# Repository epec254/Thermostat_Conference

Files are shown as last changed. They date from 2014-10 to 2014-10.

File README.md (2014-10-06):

Thermostat_Conference
=====================

## Overview

The following documents detail a 2-hour exercise, in which small teams assemble a prototype of a WiFi controllable "Smart" thermostat.  This activity was developed as a team building exercise at a corporate conference to highlight the maker movement and disruptive potential of open source hardware.  The vast majority of participants were business executives/MBAs with no technical background. The activity was successfully completed by 10 teams ranging in size from 3-10 members in 60-120 minutes, with light guidance from two facilitators.

The activity was inspired by the Spark team's blog post with an "open source" Nest: http://blog.spark.io/2014/01/17/open-source-thermostat/

Because the activity received very positive feedback, we'd like to release the documents for others to repeat.  The forums here at Spark have been incredibly helpful in development of this exercise - we've tried to reference back to specific posts, but likely forgot a few, so please accept our apologies (or, let us know and we will happily add a link).

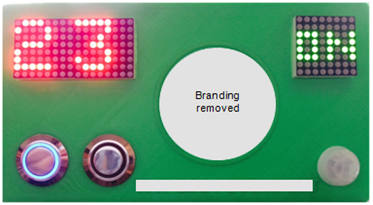
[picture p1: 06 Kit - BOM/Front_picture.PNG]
Picture of device


## Presentation
We kicked off the activity with a ~10 minute PowerPoint presentation.  Apologies for the poor formatting, it is an artifact of removing our company's branding.  I am happy to speak privately about the talk track.

## Participant materials
Each ~10 person team was given a 12 page instruction manual.  We suggested that the team's split themselves into a "hardware" and "software" group.  Progress was checked at 5 "checkpoints", where teams were measured on speed to completion.

## Participant code
Pre-written code was provided to each team.  The code corresponds to the checkpoints in the instruction manual & requires a few easy changes to be made by each team.

## Participant webapp
A HTML5 / JavaScript based interface allowed each team to view the status of / control their thermostat.  It is based on the recently released SparkJS library.  It was hacked together quickly, so I'm sure my CS professor wouldn't be so proud of the code quality ;)  I've flagged several places for future TODOs if anyone is so inclined.

## Contest tracking
As mentioned above, it was a contest to see which team could get to each checkpoint first.  To track this, in the pre-written code, a line in the setup() routine published an event to the Spark API with the team's current status.  While easily "hacked" and by no means the most elegant solution, it worked for our purposes.  An HTML file listened for the published event & displayed the timestamp for each checkpoint -- we projected this.  An (unfortunate) limitation of this HTML file is that if you refresh the page, all timestamp data is cleared.

To overcome this limitation, a node.js application listened for the same event & logged timestamps to a CSV file.  The included Excel file allows simple processing of this data to determine a winner.  Instructions for getting node.js working on Windows can be found here: https://community.spark.io/t/tutorial-spark-cli-on-windows-01-oct-2014/3112

* *Live_Status_Page.html:* HTML5 / JavaScript page that listens for each checkpoint & displays timestamps on screen (Based on: http://community.spark.io/t/multiple-cores-publishing-to-one-web-page/4161)
* *Example_Live_Results.html:* Example of what the live status page could look like post exercise
* *eventLogger.js:* Node.JS application to log the timestamps for each checkpoint (Based on https://community.spark.io/t/spark-publish-nodejs-and-eventsource-solved/3901/2)
* *Score Calculator and Dashboard vPublic.xlsx:* Excel tool to post-process data from eventLogger.js

## Pre-conference setup
To avoid potential issues and simplify, each Spark was pre-configured to a unique account & configured with a local WiFi network (instructions for how to do this can be found in the Spark documentation http://docs.spark.io/connect/).  The Spark team suggested that we use a 2.4Ghz only (e.g., turn off 5Ghz) 802.11b / g only access point with WPA2.  The access point was configured on an otherwise unused channel (e.g., at the conference center, we had IT turn off all other WiFi networks on the channel used).

## Kit / BOM
Each team needs the following components.  Note, the Adafruit LED matrixes require a small amount of soldering (<5 mins / kit).  As well, we soldered wires to the buttons for simplicity, but you could also use wire with quick connects or similar.

A basic Fritzing diagram is included.  It is for visual display only, so we only built out the breadboard tab.  We opted to not share this with participants as we thought it would be "too easy."   Our helpers had this in hand when they walked around the session in case a team was struggling - although it turned out this was unnecessary.

* (1) Spark Core: https://www.spark.io/
* (2) LED display - red: http://www.adafruit.com/products/870
* (1) LED display - green: http://www.adafruit.com/products/872
* (1 bundle) Wire bundles: http://www.adafruit.com/products/153
* (1) Cooling button: http://www.adafruit.com/products/481
* (1) Heating button: http://www.adafruit.com/products/559
* (1) USB power: http://www.adafruit.com/products/501
* (1) Temp sensor: http://www.adafruit.com/products/165
* (1) Capacitor (10000 pf): http://www.digikey.com/product-detail/en/K103K15X7RH5TL2/BC1111CT-ND/286733
* (1) Motion sensor: http://www.parallax.com/product/28033
* (15 cables) Jumper cables: Either one works, but the parallax ones have a slightly tighter fit around the LED jumper pins: http://www.parallax.com/product/800-00047 or https://www.adafruit.com/products/824
* (2) 10k ohm resistor: Purchased as part of this kit: https://www.sparkfun.com/products/10969, but any resistor will work!
* (1) 220 ohm resistor: Purchased as part of this kit: https://www.sparkfun.com/products/10969, but any resistor will work!
* (optional): USB power source, required if your participants will not have laptops to plug the Sparks into

## Thermostat enclosure
Each team was provided a 3D printed "faceplate" in which all components could be inserted.  We opted to have attendees super glue the components in place vs. "perfectly" engineer the faceplate.  For the demonstration unit, we designed a box that enclosed the entire device - great for a "wow" factor.  We used a LulzBot TAZ 4, which we would recommend, primarily due to their support team going above & beyond in helping us setup / configure the printer.

In case it helps someone, we included a version of the "faceplate" that has the beginnings of more "perfect" engineering but it is completely untested & currently not very 3D printer friendly.

The STL & Autodesk Inventor files are available.

* *Cover_Split_Top-vPublic:* "Faceplate" provided to each attendee (note - we embossed our conference name / logo but have removed here - https://github.com/epec254/Thermostat_Conference/blob/master/07%20Thermostat%20enclosure/Cover_Split_Top-vPublic.png)
* *Cover_Split_Bottom-vPublic:* Bottom of the "faceplate" to make it snap into the top of the box (printed separately and "acetone glued" to the top)
* *Box_Square_Bottom v3:* Box to enclose entire device, note that it does not fit a power source and requires you to shorten all wires (just used for the demo unit - https://github.com/epec254/Thermostat_Conference/blob/master/07%20Thermostat%20enclosure/Box_Square_Bottom%20v3.png)
* *Cover_Split_Bottom-Needs Support Material vPublic*: More "engineered" but completely untested bottom for the "faceplate"

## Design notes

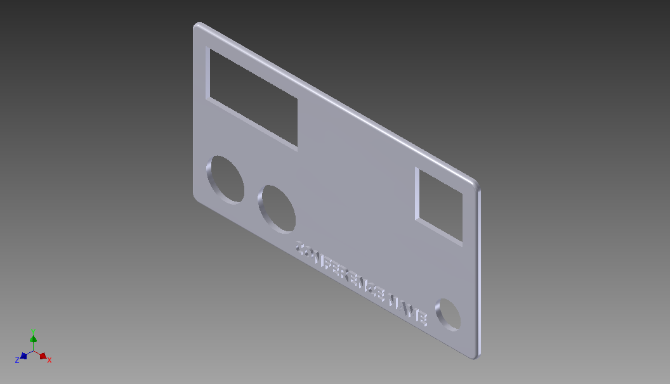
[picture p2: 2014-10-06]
07 Thermostat enclosure/Cover_Split_Top-vPublic.png

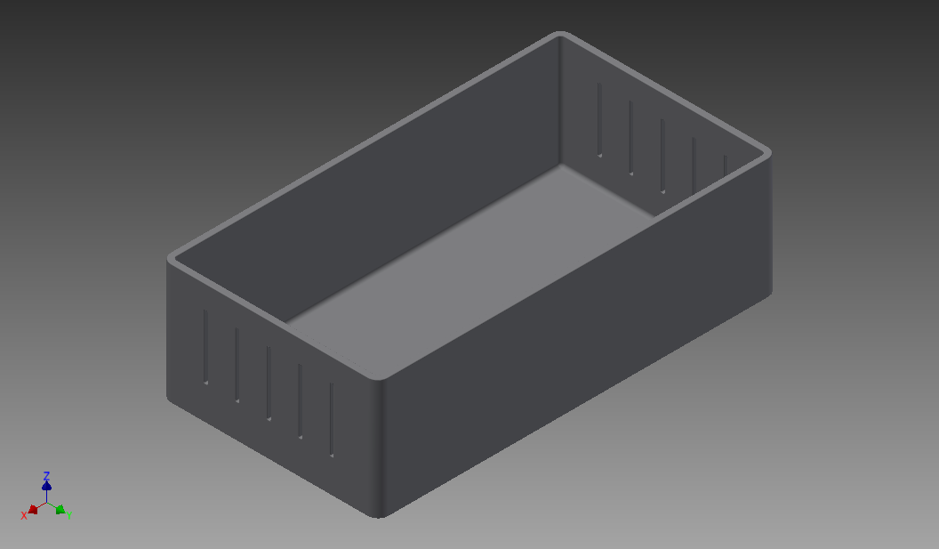
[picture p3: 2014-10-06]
07 Thermostat enclosure/Box_Square_Bottom v3.png

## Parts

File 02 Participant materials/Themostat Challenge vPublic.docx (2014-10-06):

TEAM PROGRAMMING CHALLENGE

This challenge is designed to demonstrate how widely-available open-source hardware and software can be used to quickly prototype new products. You will be using the components in front of you to build a prototype of WiFi-controllable "smart" thermostat.

The following instructions incrementally build the thermostat prototype, but there are opportunities to parallel process between the hardware assembly and software steps (each step is labeled either Hardware or Software). We suggest organizing your team into a hardware and software team.

In addition to completing the assembly and programming tasks, each team will also be required to develop a sales pitch, which will be judged qualitatively (see final steps in instructions for details).

BILL OF MATERIALS

Each kit should have the following components:

1. (1) 3D Printed mouting board

2. (1) SparkCore chip & breadboard

3. (1) Power supply & USB Charger

4. (1) Motion sensor

5. (1) Temperature sensor

6. (3) LED matrices

7. (3) Resistors

8. (2) Push buttons

9. (1) Capacitor

10. Connecting wires

11. (4) Jumper cables

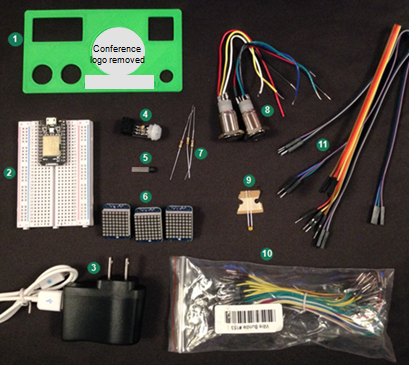
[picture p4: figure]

ACTIVITY INSTRUCTIONS

1. HARDWARE: Learning to use a breadboard

An electronics breadboard is a component to prototype circuits without the need for soldering.

Under the plastic covering, a breadboard contains horizontal and vertical rows of metal strips

The horizontal rows allow you to electrically connect a given component to any other component placed on that same row (up to 5 components), by inserting pins into the plastic pin holes. It is important to note that the 5-pin rows on each side are not connected.

The vertical strips on the left and right are called power rails and are connected across all rows. This gives the builder easy access to a power source. The power strips on both sides are also not connected.

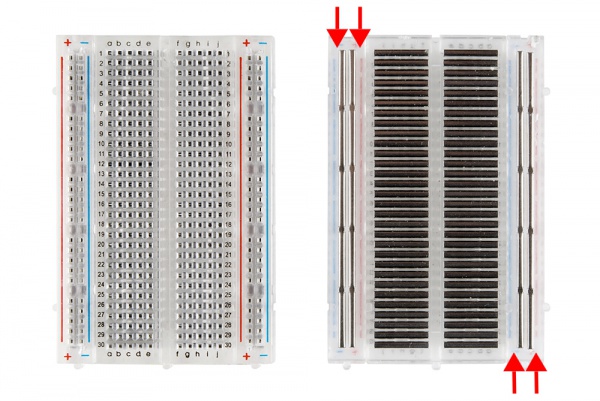
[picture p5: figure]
Front and back, medium breadboard with power rails exposed

"Connecting wires" are easily inserted into the plastic peg holes, creating circuits without soldering.

Example wiring

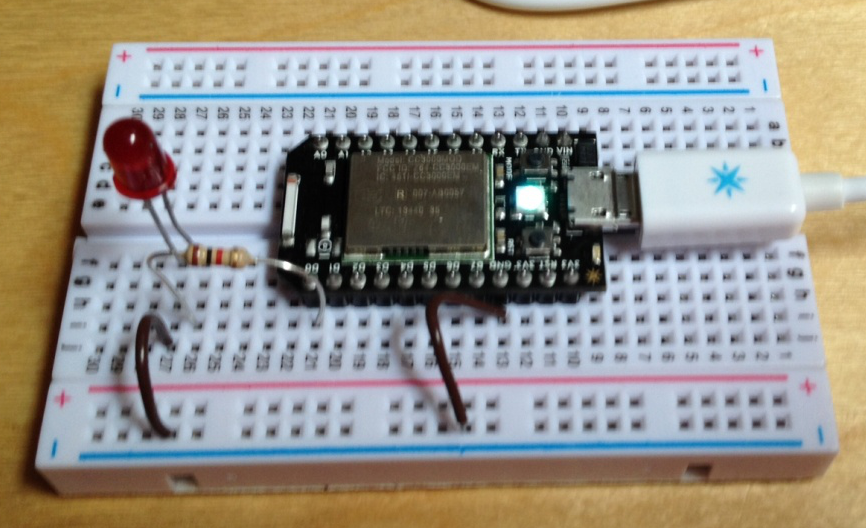
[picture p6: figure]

2. HARDWARE: Connect your SparkCore to power

2.1. Disconnect SparkCore from breadboard (gently wiggle it out) and reconnect as shown below, such that the Spark core's A0 pin aligns with the breadboard's row 12.

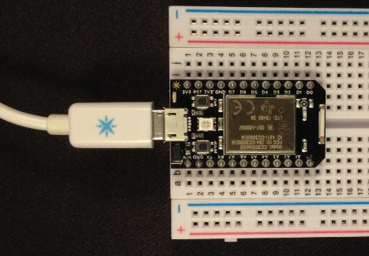
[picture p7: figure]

2.2. Connect SparkCore to power supply (connect the USB to a computer or plug included in the BOM)

  - When powered on you should see a blue "breathing" light

2.3. Do not push the two small black buttons on the SparkCore at any point (this resets the base software)

3. SOFTWARE: Upload initial software package

The Spark OS has a distributed operating system, where servers in the Cloud do the heavy lifting. That way the product can handle complex, intelligent behaviors when it's online, even with only kilobytes of memory.

4.1. Go to https://www.spark.io/build and login using the following credentials and the number that was written on your Spark's box

4.2. Name your Current App "ThermostatApp"; press enter

4.3. Now add a custom library of code to simplify our program.

- Click the Libraries icon (banner-icon 4th up from the bottom left)
- Type Therm
- Click Therm_LED_Library
- Scroll down and click "Include in App" button

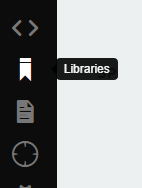
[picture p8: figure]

Now we want to add code to our device. In the spirit of open source software, we've written most of the code for you.

4.4. Go to Step1.cpp and copy the entire block of code

4.5. Return to the Spark build website and paste code into your "Current App" replacing all existing code

- The top of the window where you are pasting code should say "thermostatapp.ino"

4.6. In line 9 of the code, change your CoreID to match the number written on the Spark's box (e.g. 7)

4.7. In line 10 of the code, change your TeamName to something creative and unique! (This will appear on the leader board projected in the room)

- E.g. char *teamName = "Witty Team Name"; //max length 20 characters!!!

4.8. Click the verify logo (second down from top) to confirm your code compiles correctly; you should see "Code Verified! Great work" message on bottom right

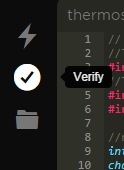
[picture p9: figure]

4.9. Click the flash button (see image below) to send your new code to your Spark (this will take a moment)

- The light on the spark chip will go through a series colors and blinking (it will first flash purple), before returning to blue "breathing"

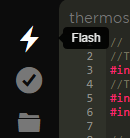
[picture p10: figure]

Color code:

- Flashing green: Connecting to Wi-Fi network
- Flashing cyan: Connecting to Spark Cloud
- Breathing cyan: Connected to Spark Cloud
- Flashing purple: Updating firmware

_____________________________________________________________________________________

!!! CHECK-POINT #1 !!!

Congrats, you've earned your first points!

In the next 60 seconds, the dashboard projected in the room should show that your team has completed this step.

_____________________________________________________________________________________

5. HARDWARE: Connecting temperature chip to your breadboard

You're now ready to connect your first component to your breadboard!

5.1. Connect the breadboard's (-) power rail to SparkCore's GND connection point using a connecting wire

5.2. Connect the breadboard's (+) power rail to SparkCore's 3V3* connection point using a connecting wire (make sure it is 3V3*, not 3V3), (hint the wire will arc over the chip)

5.3. Insert temperature sensor's three pins into breadboard's B28, B29, B30

5.4. Connect temperature chip's Pin1 and Pin3 to appropriate power rails using connecting wires (see graphic below)

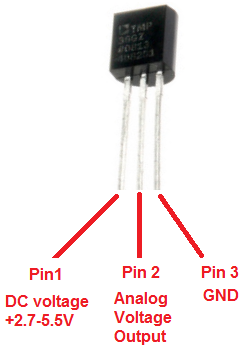
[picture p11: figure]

5.5. Insert capacitor (see BOM) connecting breadboard's ground power rail on A-E side of board, to breadboard's A5

5.6 . Using a connecting wire, connect Pin2 of temperature chip to spark core's A7 (your connecting wire should be placed into breadboard's B5)

You now need to sync with the software team to update the device's software and read the temperature! They will need to know what Spark pin you have connected the temperature sensor to.

_____________________________________________________________________________________

!!! CHECK-POINT #2 !!!

In the next 60 seconds, the dashboard projected in the room should show that your team has completed this step.

_____________________________________________________________________________________

6. SOFTWARE: Reading temperature from device

You're now ready to wirelessly flash new software to your device and read the temperature!

6.1. Go to Step2.cpp and copy the block of code

6.2. Return to the Spark build website and paste code into your "Current App" replacing all existing code

- Recall, the top of the window where you are pasting code should say "thermostatapp.ino"

6.3. In the code, change the following (prior changes are lost when new code updated, sorry!)

- Line9: Change your CoreID to match the number written on your Spark's box (e.g. 7)
- Line10: Update your TeamName again

6.4. In line 16 of the code, you need to replace the "xx" with Spark's connection point that the thermostat's output wire is connected to. Ask your Hardware team for this information based on what they completed in step 5. Do not use quotes (e.g. #define THERM_PIN A3)

6.5. Click the verify button (second down from top) to confirm your code compiles correctly; you should see "Code Verified! Great work" message on bottom right.

6.6. Click the flash button (see image below) to send your new code to your Spark (this will take a moment)

- The light on the spark chip will go through a series colors and blinking (it will first flash purple), before returning to blue "breathing"

7. SOFTWARE: Mobile Access

Because your device is cloud connected, you can access it from any mobile device. To demonstrate this we've set up a simple mobile website available <insert website location>

7.1. Open the website

7.2. Login using your credentials from your BOM

7.3. Confirm the temperature on your phone your previous/current reading

Congrats! You've built a WiFi-accessible thermometer! But we can do more!

_____________________________________________________________________________________

!!! CHECK-POINT #3 !!!

In the next 60 seconds, the dashboard projected in the room should show that your team has completed this step.

_____________________________________________________________________________________

8. HARDWARE: Connecting LED Matrices

Now we'd like to be able to display the temperature directly to the device.

8.1. Connect 4-stranded jumper cables to your three LED Matrices (order does not matter, but push hard to ensure connection is made)

8.2. Connect the LED's +/- and negative connection points to your power strips in rows ~21-23 using the jumper cables (Do this for all three LED matrices)

- Look at the top of the LED matrix to match the given jumper cable strand to its connection point.
- You may want to tear back the wires/apart some to give you more room to manipulate


8.3 For each LED Matrix, connect its "C" connection point to row 21 on the A-E side of the breadboard; For "D" connection point, connect to row 22.

8.4. Create a connection between the LED Matrix pin "C" and Spark's D1 (should be breadboard's row 11) using a connecting wire via rows 21.

8.5. Create a connection between the LED Matrix pin "D" and Spark's D0 (should be breadboard's row 12) using a connecting wire via rows 22.

LED trouble shooting: If an LED is not working, disconnect the Spark's power source and reconnect.

You now need to sync with your software team. They will need to know what Spark pins you have connected the LEDs to.

9. SOFTWARE: Display temperature on LED Matrix

We need to update the code to utilize the hardware team's new LED matrices.

9.1. Go to Step3.cpp and copy the block of code

9.2. Return to the Spark build website and paste code into your "Current App" replacing all existing code

9.3. In the code, change the following (prior changes are lost when new code updated, sorry!)

- Line 9: Update your CoreID
- Line 10: Update your TeamName

9.4. Now update Lines 17 and 18 for I2C_D and I2C_C. To update these ask your hardware team which of Spark's PINs they connected to the LED matrices' C and D connection points.

- For example, if the hardware team advised it was connected to A0, the code be: #define I2C_D A0

9.5. Click the verify logo (second down from top) to confirm your code compiles correctly

9.6. Click the flash button to send your new code to your Spark (this will take 15-30 seconds and the devices will flash purple)

_____________________________________________________________________________________

!!! CHECK-POINT #4 !!!

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

_____________________________________________________________________________________

10. HARDWARE: Wire buttons to set temperature

Next we want the ability to set the temperature vs. read it. We'll add two buttons to do this.

10.1. Connect the breadboard's other power strips (the F-J side) to Spark's GND and 3V3* connection points using connecting wires.

10.2 Unscrew nut from bottom of push button; pass wires through front of 3D printed mounting board; re-thread nut (place blue-LED to left; Red to right)

10.3. Connect the black wires from both push buttons to the ground power rail (suggest rows 29/30 on F-J side)

10.4. Connect the red power wire directly to breadboard holes…(DO NOT CONNECT TO POWER RAIL)

- For blue button, connect to breadboard i7 (which should connect to Spark's D5 connection point)
- For red button, connect to breadboard i6 (which should connect to Spark's D6 connection point)

10.5. Find the wire on each button that is closest to the black ground wire (color should be white or blue), and plug it into the + power rail (suggest ~rows 15/16 on F-J side)

10.6. Now we need to connect a resistor to the board to limit the flow of electricity through the circuit (this is known as a pull down resistor, but we don't need to get into the details).

- Find the (2) identical resistors in your BOM with the black stripe
- Plug one end of the resistor into the ground power rail (F-J side) and the other end into row 24 (rows F-J); with the second resistor, do the same between the ground power rail and row 27.

10.7. Complete the circuit using the button, resistor, and spark

- For the blue push button, take the remaining unattached wire and connect to breadboard's row 27 (F-J side)
- For blue push button, use a connecting wire to complete the circuit to Spark's D2 (should be at breadboard's row 10) connection point from breadboard's row 27
- For the red push button, take the remaining unattached wire and connect to breadboard's row 24 (F-J side)
- For red push button, use a connecting wire to complete the circuit to Spark's D3 (should be at breadboard's row 9) connection point from breadboard's row 24

11. SOFTWARE: Set temperature

We need to update the code to utilize the hardware team's new push buttons.

11.1. Go to Step4.cpp and copy the block of code

11.2. Return to the Spark build website and paste code into your "Current App" replacing all existing code

11.3. In the code, change the following (prior changes are lost when new code updated, sorry!)

- Line 9: Update your CoreID
- Line 10: Update your TeamName

11.4. Click the verify logo (second down from top) to confirm your code compiles correctly

11.5. Click the flash button to send your new code to your Spark (this will take a moment)

_____________________________________________________________________________________

!!! CHECK-POINT #5 !!!

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

_____________________________________________________________________________________

12. HARDWARE: Connect motion sensor device

Lastly, we want to add a motion sensor so we can introduce logic based on the activity around the device.

12.1. Connect motion sensor to 3–stranded jumper cable (you may want to tear back the wires to give you more room to manipulate them)

12.2. Thread the jumper cables through the front of the 3D printed mounting board.


12.3. Connect the motion sensor's "VDD" point to power (+) on the breadboard's F-J side (suggest row ~5)

12.4. Connect the motion sensor's "GND" point to ground (-)on the breadboard's F-J side (suggest row ~5)

12.5. Find the remaining resistor (Red-Red-Brown-Gold) and connect breadboard's G15 and G17

12.6 Connect the remaining jumper cable strand (motion sensor's "Out") to F15

12.7 Use a connecting wire to connect breadboard's F17 to Spark's D4 (should be breadboard's row 8)

Congrats, your hardware is now fully wired! You need to speak with your software team to tell them where you've wired the motion sensor.

13. SOFTWARE: Motion sensor

We need to update the code to utilize the hardware team's motion sensor.

13.1. Go to Step5.cpp and copy the block of code

13.2. Return to the Spark build website and paste code into your "Current App" replacing all existing code

13.3. In the code, change the following (prior changes are lost when new code updated, sorry!)

- Line 9: Update your CoreID
- Line 10: Update your TeamName

13.4. Now update Line 25 with the Spark pin that the hardware team connected the motion sensor to.

- For example, if the hardware team advised it was connected to A0, the code be: #define Motion A0

13.4. Click the verify logo (second down from top) to confirm your code compiles correctly

13.5. Click the flash button to send your new code to your Spark (this will take a moment)

_____________________________________________________________________________________

!!! CHECK-POINT #5 !!!

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

_____________________________________________________________________________________

14. Final assembly

14.1. Use super glue (shared across groups) to fix your LEDs and motion sensor to the mounting board

14.2. Gently bend wires to stand display upright. Take a picture and smile.

The electronics of your prototype could be encased into a 3D printed housing (see sample).

Appendix: Example circuits (not part of this design)


Programming Activity

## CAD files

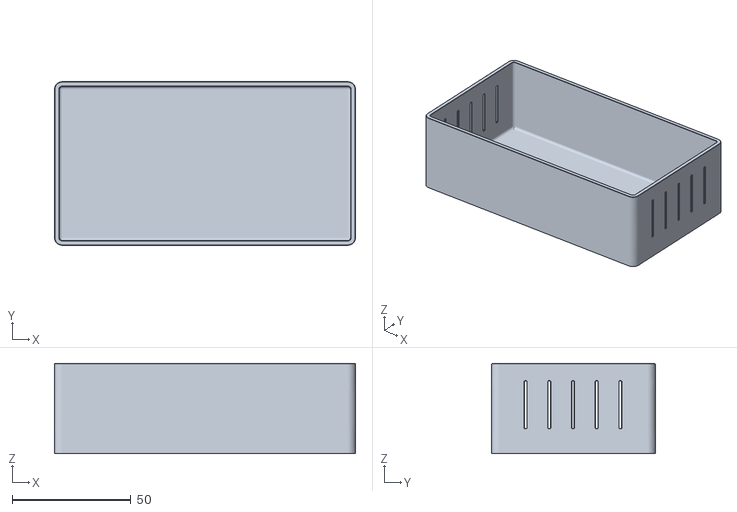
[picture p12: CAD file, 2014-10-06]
07 Thermostat enclosure/Box_Square_Bottom v3.stl
127.0 x 69.0 x 38.1

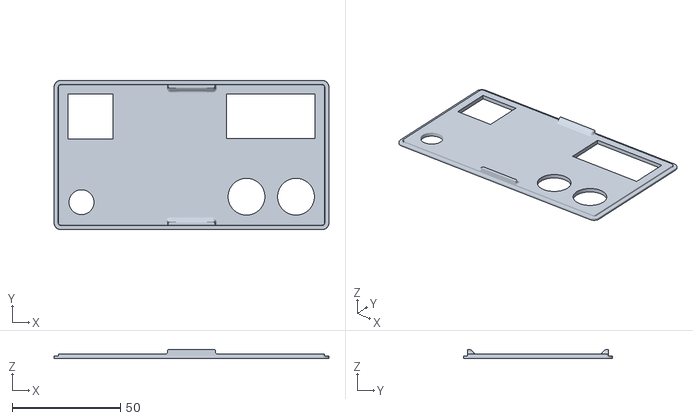
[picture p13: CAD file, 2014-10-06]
07 Thermostat enclosure/Cover_Split_Bottom-vPublic.stl
127.0 x 69.0 x 4.00

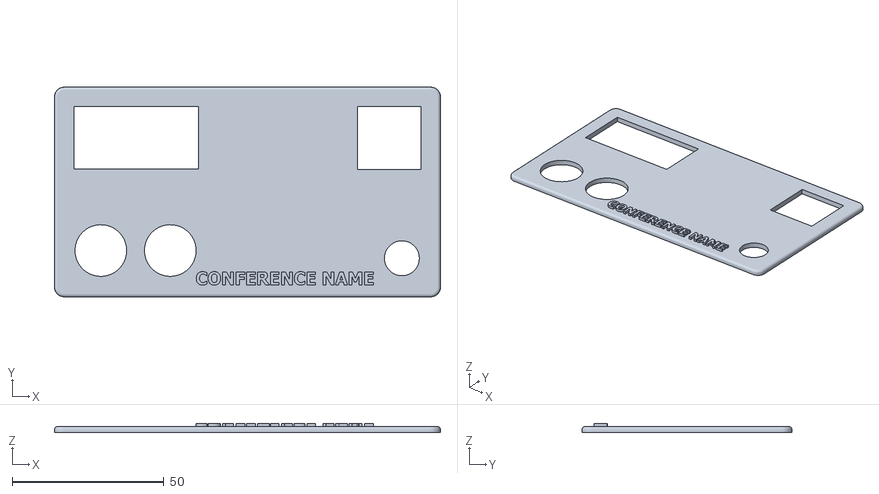
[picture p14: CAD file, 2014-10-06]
07 Thermostat enclosure/Cover_Split_Top-vPublic.stl
127.0 x 69.0 x 3.00

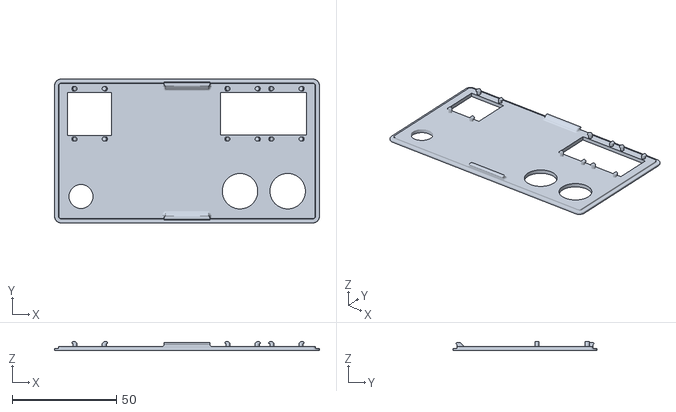
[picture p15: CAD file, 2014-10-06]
07 Thermostat enclosure/Cover_Split_Bottom-Needs Support Material vPublic.stl
127.0 x 69.0 x 4.53

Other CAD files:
07 Thermostat enclosure/Box_Square_Bottom v3.ipt
07 Thermostat enclosure/Cover_Split_Bottom-Needs Support Material vPublic.ipt
07 Thermostat enclosure/Cover_Split_Bottom-vPublic.ipt
07 Thermostat enclosure/Cover_Split_Top-vPublic.ipt

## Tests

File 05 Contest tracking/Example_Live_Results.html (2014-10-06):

#### Team status

Team Name | Team ID | Stage 1 | Stage 2 | Stage 3 | Stage 4 | Stage 5
A perfect fit | 10 | 2014-10-02T08:47:07.987Z | 2014-10-02T08:58:47.705Z | 2014-10-02T09:12:10.074Z | 2014-10-02T09:30:01.328Z | 2014-10-02T09:40:57.122Z
Absolute Zeroes | 14 | 2014-10-02T08:49:00.809Z | 2014-10-02T08:57:44.260Z | 2014-10-02T09:05:05.363Z | 2014-10-02T09:07:30.058Z | 2014-10-02T09:21:38.371Z
BlueAngels | 11 | 2014-10-02T08:50:24.151Z | 2014-10-02T08:52:48.805Z | 2014-10-02T09:01:32.420Z | 2014-10-02T09:05:04.780Z | 2014-10-02T09:13:53.456Z
Winning23 | 23 | 2014-10-02T08:50:41.940Z | 2014-10-02T08:54:45.386Z | 2014-10-02T09:05:01.194Z | 2014-10-02T09:11:01.475Z | 2014-10-02T09:15:49.706Z
Thermax | 22 | 2014-10-02T08:56:06.512Z | 2014-10-02T08:59:56.194Z | 2014-10-02T09:08:16.548Z | 2014-10-02T09:17:43.936Z | 2014-10-02T09:21:41.329Z
SmrtBOX | 21 | 2014-10-02T08:57:30.716Z | 2014-10-02T09:00:52.324Z | 2014-10-02T09:14:02.205Z | 2014-10-02T09:16:55.191Z | 2014-10-02T09:23:53.116Z
Nested-If | 24 | 2014-10-02T08:58:45.391Z | 2014-10-02T09:06:50.470Z | 2014-10-02T09:19:46.422Z | | 2014-10-02T09:35:23.522Z
iMeter | 13 | | 2014-10-02T09:03:34.880Z | 2014-10-02T09:15:04.473Z
Thermonator | 9 | 2014-10-02T09:16:35.565Z

Running

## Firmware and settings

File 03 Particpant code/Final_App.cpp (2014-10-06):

// This #include statement was automatically added by the Spark IDE.
//This will allow for future support of the LED matrixes
#include "Therm_LED_Library/Therm_LED_Library.h"
//These next 2 lines are required by spark
#include "application.h"
#include <math.h>

//now we will declare your team name
int core_id = 1; //change to your spark team ID (1 - 30)
char *teamName = "Demo Unit"; //max length 20 characters!!!

//now you need to ask your hardware team what PIN your different items are on 
//change XX in the code below to the pin number, e.g., D6, etc
//(if your hardware team tells you thermostat is connected to D6 code would be as follows)
//#define THERM_PIN   D6
//button toggles
#define COOL_BUTTON D2
#define HEAT_BUTTON D3
//LEDs within the buttons
#define COOL_LED D5
#define HEAT_LED D6
//Thermometer
#define THERM_PIN   A7
//Motion sensor
#define MOTION D4

//static definitions to identify which pin belongs to which device
//DO NOT CHANGE
#define MATRIX1_I2C 0x70
#define MATRIX2_I2C 0x71
#define MATRIX3_I2C 0x72
#define I2C_D D0
#define I2C_C D1
#define MAX_TEMP 40
#define MIN_TEMP 0
#define DESIRED_TEMP_FLASH_ADDRESS 0x80000
Adafruit_8x8matrix matrix1;
Adafruit_8x8matrix matrix2;
Adafruit_8x8matrix matrix3;

//DO NOT CHANGE THESE NEXT LINES
//These store the current state of the program
//variable to store current temperature (the room)
int currentTemperature = 0;
//variable to store desired temperature (the setting)
int desiredTemperature = 0;
//should the heat be on?
bool isHeatOn = false;
//should the AC be on?
bool isCoolOn = false;
//is motion currently detected?
bool motionDetected = false;
//last time motion detected
unsigned long lastMotionSensed = 0UL;
//UNIX timestamp of last motion sense
int lastMotionTimeStamp = 0;
//to log data via google apps
char logResult[200] = "";
//to allow motion to only be published to the cloud once every 15 seconds
unsigned long lastMotionPublish = 0UL;
char idForPublishMotion[2] = "";
//last state of cool / heat buttons
int lastHeatButtonState = 0;
int lastCoolButtonState = 0;
//to allow thermostat to turn on / off
//true = on; false = off
bool thermostatStatus = true;
//status variable
char statusString[100] = "";
char *contestStatus = "step5";

static const uint8_t on_motion[] = {
    0b11111111,
    0b00000000,
    0b11101001,
    0b10101101,
    0b10101011,
    0b11101001,
    0b00000000,
    0b11111111
};

static const uint8_t off_motion[] =
{   0b11111111,
    0b00000000,
    0b11101111,
    0b10101000,
    0b10101111,
    0b11101000,
    0b00000000,
    0b11111111 };

static const uint8_t on_nomotion[] =
{   0b00000000,
    0b00000000,
    0b11101001,
    0b10101101,
    0b10101011,
    0b11101001,
    0b00000000,
    0b00000000 };
static const uint8_t off_nomotion[] =
{   0b00000000,
    0b00000000,
    0b11101111,
    0b10101000,
    0b10101111,
    0b11101000,
    0b00000000,
    0b00000000 };

void displayTemperature(void);
void saveTemperature();
void loadTemperature();
int setTemperature(int t);
int setTemperatureFromString(String t);
void setupMatrix(Adafruit_8x8matrix m);
int adjustThermostatStatus(String status);



//run by the Spark Core upon start - configures all PINs & web interface
void setup()
{
    Wire.begin();
    
    //initial setup of the LED matrixes
    matrix1.begin(MATRIX1_I2C);
    matrix2.begin(MATRIX2_I2C);
    matrix3.begin(MATRIX3_I2C);
    
    setupMatrix(matrix1);
    setupMatrix(matrix2);
    setupMatrix(matrix3);
    
    //allow temperature to be set via web interface
    Spark.function("set_temp", setTemperatureFromString);
    
    //allow thermostat to be turned on / off from web interface
    Spark.function("set_status", adjustThermostatStatus);
    
    //allow temperature (room & setting) to be read from web interface
    Spark.variable("current_temp", &currentTemperature, INT);
    Spark.variable("desired_temp", &desiredTemperature, INT);
    
    //allow status of heating & cooling & motion to be read from web interface
    Spark.variable("is_heat_on", &isHeatOn, BOOLEAN);
    Spark.variable("is_cool_on", &isCoolOn, BOOLEAN);
    Spark.variable("motion", &motionDetected, BOOLEAN);
    
    //Variable that Google docs will read
    Spark.variable("log_data", &logResult, STRING);
    
    Serial.begin(9600);
    
    loadTemperature();
    
    //LED pins send voltage (OUTPUT)
    pinMode(COOL_LED, OUTPUT);
    pinMode(HEAT_LED, OUTPUT);
    
    //themometer pin recieves voltage (INPUT)
    pinMode(THERM_PIN, INPUT);
    
    //temp setting buttons recieve voltage (INPUT)
    pinMode(COOL_BUTTON, INPUT);
    pinMode(HEAT_BUTTON, INPUT);
    
    //motion senior recieves voltage (INPUT)
    pinMode(MOTION, INPUT);
    
    //default LEDs to off
    digitalWrite(COOL_LED,LOW);
    digitalWrite(HEAT_LED,LOW);
    
    sprintf(statusString, "{\"id\":%d,\"team\":\"%s\",\"contest_status\":\"%s\"}", core_id, teamName, contestStatus);
    Spark.publish("contest-status",statusString);
}



void loop()
{
    //counter to allow us to only check the temp every so often
    static int wait = 0;
    
    static int firstTimeOn = 1;
    
    int tempReading = 0;
    double voltage = 0.0;
    
    int motionReading = 0;
    
    int heatButtonState = 0;
    int coolButtonState = 0;
    
    
    //only check & update temp every so often
    if (!wait)
    {
        wait = 1000;
        
        //TEMPERATE READING
        //read temp raw data
        tempReading = analogRead(THERM_PIN);
        voltage = (tempReading * 3.3) / 4095;
        //get the temp as degrees C
        double doubleTemp = (voltage - 0.5) * 100;
        //convert c to f
        //doubleTemp = ((doubleTemp * 9) / 5) + 32;
        // cast to int (e.g., change 75.44 to 75)
        currentTemperature = round(doubleTemp);
    }
    
    //MOTION READING
    motionReading = digitalRead(MOTION);
    if (motionReading == HIGH) {
        motionDetected = true;
        //store last time sensed
        lastMotionSensed = millis();
        lastMotionTimeStamp = Time.now();
        
        //only publish every 15 seconds
        unsigned long now = millis();
        if ((now - lastMotionPublish)>15000UL) {
            sprintf(idForPublishMotion, "%d", core_id);
            Spark.publish("contest-motion",idForPublishMotion);
            lastMotionPublish = now;
        }
    } else {
        motionDetected = false;
    }
    
    
    //BUTTONS FOR TEMP ADJUSTMENT
    heatButtonState = digitalRead(HEAT_BUTTON);
    coolButtonState = digitalRead(COOL_BUTTON);
    
    if(heatButtonState == HIGH) { //button pressed
        
        if (lastHeatButtonState != heatButtonState) { //changed from previous state
            //this logic prevents erratic behavior from the user holding the button down
            //TODO: Implement logic to allow user to hold button down for quick changes
            
            //change the temperature
            if (desiredTemperature < MAX_TEMP) {
                setTemperature(desiredTemperature + 1);
            }
        }
        
        //save last button state
        lastHeatButtonState = heatButtonState;
    } else { //button not pressed
        //save last button state
        lastHeatButtonState = heatButtonState;
        
    }
    
    if(coolButtonState == HIGH) { //button pressed
        if (lastCoolButtonState != coolButtonState) { //changed from previous state
            //this logic prevents erratic behavior from the user holding the button down
            //TODO: Implement logic to allow user to hold button down for quick changes
            
            //change the temperature
            if (desiredTemperature > MIN_TEMP) {
                setTemperature(desiredTemperature - 1);
            }
        }
        
        //save last button state
        lastCoolButtonState = coolButtonState;
    } else { //button not pressed
        //save last button state
        lastCoolButtonState = coolButtonState;
        
    }
    
    //DISPLAY STATUS & MOTION
    matrix3.clear();
    if (motionDetected == true && thermostatStatus == true) {
        //on & motion
        matrix3.drawBitmap(0, 0, on_motion, 8, 8, LED_ON);
    } else if (motionDetected == true && thermostatStatus == false) {
        //off & motion
        matrix3.drawBitmap(0, 0, off_motion, 8, 8, LED_ON);
    } else if (motionDetected == false && thermostatStatus == true) {
        //on & NO motion
        matrix3.drawBitmap(0, 0, on_nomotion, 8, 8, LED_ON);
    } else if (motionDetected == false && thermostatStatus == false) {
        //off & NO motion
        matrix3.drawBitmap(0, 0, off_nomotion, 8, 8, LED_ON);
    }
    matrix3.writeDisplay();
    
    
    
    //ADJUST THE HEATING / COOLING ELEMENTS
    isHeatOn = desiredTemperature > currentTemperature;
    if(isHeatOn == true && thermostatStatus == true)
    {
        digitalWrite(HEAT_LED, HIGH);
        
    }
    else
    {
        digitalWrite(HEAT_LED, LOW);
    }
    
    
    isCoolOn = desiredTemperature < currentTemperature;
    
    if(isCoolOn == true && thermostatStatus == true)
    {
        digitalWrite(COOL_LED, HIGH);
        
    }
    else
    {
        digitalWrite(COOL_LED, LOW);
    }
    
    
    //logging result for Google
    sprintf(logResult, "{\"id\":%d,\"team\":\"%s\",\"c_tmp\":%d,\"d_tmp\":%d,\"motion\":\"%s\",\"heat\":\"%s\",\"cool\":\"%s\",\"status\":\"%s\",\"last_motion\":%d,\"contest_status\":\"%s\"}", core_id, teamName, currentTemperature, desiredTemperature, ((millis() - lastMotionSensed) < 5000UL)  ? "true" : "false", isHeatOn ? "true" : "false", isCoolOn ? "true" : "false", thermostatStatus ? "on" : "off", lastMotionTimeStamp, contestStatus);
    

    --wait;
}


//HELPER FUNCTIONS BELOW - DO NOT MODIFY

//function to turn thermostat on / off from web interface
int adjustThermostatStatus(String status)
{
    
    if (status == "on" && thermostatStatus == false)
    {
        //if off, turn on
        thermostatStatus = true;
        Serial.print("Turn thermostat to status on");
        return 1;
    } else if (status == "off" && thermostatStatus == true)
    {
        //if on, turn off
        thermostatStatus = false;
        Serial.print("Turn thermostat to status off");
        return 0;
    } else if (status == "on" || status == "off")
    {
        //valid command, but no need to adjust status
        return -1;
    } else
    {
        //invalid command, do nothing
        return -2;
    }
    
}


//function to display the room temperate on the LED boards
void displayTemperature(void)
{
    char ones = desiredTemperature % 10;
    char tens = (desiredTemperature / 10) % 10;
    
    matrix1.clear();
    matrix1.setCursor(0, 0);
    matrix1.write(tens + '0');
    matrix1.writeDisplay();
    
    matrix2.clear();
    matrix2.setCursor(0, 0);
    matrix2.write(ones + '0');
    matrix2.writeDisplay();
}

//helper function to save the desired temperate set by user
void saveTemperature()
{
    sFLASH_EraseSector(DESIRED_TEMP_FLASH_ADDRESS);
    Serial.println("Saving temperature to flash");
    uint8_t values[2] = { (uint8_t)desiredTemperature, 0 };
    sFLASH_WriteBuffer(values, DESIRED_TEMP_FLASH_ADDRESS, 2);
}

//helper function to load the desired temperate set by user
void loadTemperature()
{
    Serial.println("Loading and displaying temperature from flash");
    uint8_t values[2];
    sFLASH_ReadBuffer(values, DESIRED_TEMP_FLASH_ADDRESS, 2);
    desiredTemperature = values[0];
    displayTemperature();
}

//function for adjusting the temperate
int setTemperature(int t)
{
    desiredTemperature = t;
    displayTemperature();
    saveTemperature();
    return desiredTemperature;
}

//wrapper function for adjusting the temperate from the web interface
int setTemperatureFromString(String t)
{
    
    Serial.print("Setting desired temp from web to ");
    Serial.println(t);
    
    if (t.toInt() < MIN_TEMP || t.toInt() > MAX_TEMP) {
        //sanity check, if outside of given range, ignore it (will also catch strings)
        //TODO: More robust input validation!  (for those who understand security - you will immediatly recognize how insecure this unchecked input is!)
        return -1;
    } else {
        return setTemperature(t.toInt());
    }
}

//helper function to set up the matrixes
void setupMatrix(Adafruit_8x8matrix m)
{
    m.clear();
    m.writeDisplay();
    m.setTextSize(1);
    m.setTextWrap(false);
    m.setTextColor(LED_ON);
    m.setRotation(0);
    m.setCursor(0, 0);
}

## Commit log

2014-10-06 cad files
    [Box_Square_Bottom v3.ipt, Box_Square_Bottom v3.stl, Cover_Split_Bottom-Needs Support Material vPublic.ipt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]
2014-10-06 changes to readme
    details about power source in BOM, limitations of 3d box as designed
